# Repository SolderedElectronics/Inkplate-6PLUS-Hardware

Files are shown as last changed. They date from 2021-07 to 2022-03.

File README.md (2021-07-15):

# Inkplate 6PLUS Open Source Hardware files



Open Source Hardware (OSH) files for e-paper display Inkplate 6PLUS can be found in this repo. Inkplate 6PLUS is a powerful, energy-efficient, Wi-Fi-enabled ESP32 board with a recycled 6.0 inch e-paper display featuring touchscreen and front lighting. It is part of Inkplate family and it’s open hardware supported by an open-source software library, and it’s the easiest e-paper board to use, regardless of whether you prefer the Arduino IDE or MicroPython. Learn more about Inkplate 6PLUS on [Crowd Supply](https://www.crowdsupply.com/e-radionica/inkplate-6plus) or [official website](https://inkplate.io).

### Versions:
- v1.0. first, original version shipped to backers in 2021

### Misc
Inkplate 6PLUS is available for purchase via:
- [e-radionica.com](https://e-radionica.com/en/inkplate.html)
- [Crowd Supply](https://www.crowdsupply.com/e-radionica/inkplate-6PLUS)

For all questions and issues, please open an issue or thread on [our forums](http://forum.e-radionica.com/en/).
For sales & collaboration, please reach us via [e-mail](mailto:kontakt@e-radionica.com).

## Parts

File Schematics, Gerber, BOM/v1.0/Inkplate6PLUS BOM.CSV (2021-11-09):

Bill of Material for
On 9/14/2021 at 11:42:50 AM
Comment | Pattern | Quantity | Components
0R | 0603R | 1 | R11
100k | 0603R | 13 | R10, R22, R24, R25, R26, R29, R30, R33, R37, R38, R40, R41, R42
100nF - AC0603KRX7R8BB104 | 0603C | 2 | C14, C15
100nF | 0603C | 22 | C22, C23, C24, C27, C28, C31, C32, C34, C37, C38, C40, C43, C44, C48, C49, C50, C55, C59, C62, C64, C65, C66
100pF | 0603C | 1 | C33
10K | 0603R | 6 | R3, R4, R17, R21, R28, R39
10nF-AC0603KRX7R8BB103 | 0603C | 2 | C16, C17
10uF | 1206C | 3 | C20, C26, C42
10uF-GRM188R61E106KA73J | 0603C | 3 | C7, C9, C13
1206FUSE_500mA | 1206FUSE | 1 | F1
12pF | 0603C | 2 | C46, C47
15R | 0603R | 1 | R34
1K | 0603R | 6 | R9, R15, R27, R31, R32, R43
1M | 0603R | 2 | R5, R6
1uF | 0603C | 2 | C45, C53
2/3 pads connected | SMD_JUMPER 2/3 pads | 3 | JP1, JP2, JP4
2K49 | 0603R | 1 | R18
2u2 | 0603C | 6 | C21, C29, C30, C36, C39, C41
2u2-GRM188R61E225MA12D | 0603C | 2 | C18, C19
330R | 0603R | 1 | R14
3V3 | HEADER MALE 1x1 - NO_SILK | 1 | K21
43k-RC0603FR-0743KL | 0603R | 1 | R2
470R | 0603R | 1 | R13
47k | 0603R | 1 | R36
47k5-RC0603FR-0747K5L | 0603R | 1 | R7
4u7 | 0603C | 2 | C51, C52
4u7-TMK212AB7475KG-T | 0805C | 15 | C1, C2, C3, C4, C5, C6, C8, C10, C11, C12, C54, C58, C60, C61, C63
510K | 0603R | 1 | R16
52k3-RC0603FR-0752K3L | 0603R | 1 | R8
5k1 | 0603R | 3 | R19, R20, R35
7LC32768F12UC | 3215Crystal | 1 | X1
AP5726WG-7 | SOT-23-6 | 1 | U10 | inkplate 6+
BAT20J | SOD-323 | 1 | D8
BAT54S | SOT-23-3 | 4 | D3, D4, D5, D6 | SINGLE SHOTTKY DIODE
CH340C | SOP-16 | 1 | U9
CL21B105KBFNNNG | 0805C | 2 | C56, C57
CR2032-BS-6-1 | CR2032-BS-6-1 | 1 | K33
CUS10F30,H3F | SOD-323 | 2 | D1, D2
DIODA M4 | DIODA SMA | 2 | D9, D10
DNP | 0603R | 2 | R12, R23
DNP | 2917C | 2 | C25, C35
DNP | SOT-23-3 | 1 | Q1
easyC SMD | EasyC connector | 1 | K22
ESP32-WROVER | ESP32-WROVER | 1 | U3
GND | HEADER MALE 1x1 - NO_SILK | 1 | K26
GPB1 | HEADER MALE 1x1 - NO_SILK | 1 | K1
GPB5 | HEADER MALE 1x1 - NO_SILK | 3 | K9, K11, K15
HEADER 1x1 | HEADER MALE 1x1 - NO_SILK | 17 | K2, K3, K4, K5, K6, K7, K8, K10, K12, K13, K14, K16, K17, K18, K19, K27, K28
HEADER 8x1 | HEADER MALE 8x1 - NO_SILK | 2 | K20, K23
HYC77-TF09-200 | HYC77-TF09-200 | 1 | K29 | MicroSD Inkplate
Inkplate_TP | Inkplate test header | 1 | K36
JST 2pin | JST 2PIN SMD | 1 | K30
K2-1114SA-A4SW-06 | K2-1114SA-A4SW-06 | 2 | S2, S4 | Inkplate
KILL | HEADER MALE 1x1 - NO_SILK | 1 | K32
left connection | SMD_JUMPER 2/3 pads left connection | 1 | JP3
LQH44PN4R7MP0L | LQH44PN4R7MP0_Inductor | 1 | L1 | Inductor Power Chip Shielded Wirewound 4.7uH 20% 1MHz Ferrite 1.7A 96mOhm DCR 1515 Embossed T/R
LTST-S270TBKT | 0603 Side view LED LTST-S270GKT | 1 | D12
MC14093BDTR2G | TSSOP-14 | 1 | U8 | Inkplate
MCP23017T-E/SS | SSOP-28 10.20x5.30mm | 2 | U2, U4
MCP47A1T-A0E/LT | MCP47A1 SOT-23-6 | 1 | U11 | Inkplate 6+
MCP73831T-2ACI/OT | SOT-23-5 | 1 | Q3
NMOS | SOT-23-3 | 2 | Q6, Q13
NPN | SOT-23-3 | 3 | Q4, Q7, Q9
NR4012T220M | NR4012T2R2M_Fixed Inductor | 1 | L3 | FIXED IND 2.2UH 1.2A 108 MOHM
NR4012T2R2M | NR4012T2R2M_Fixed Inductor | 1 | L2 | FIXED IND 2.2UH 1.2A 108 MOHM
NTC-NCP18XH103F03RB | 0603R | 1 | R1
PAD | PAD4x4 | 9 | PAD1, PAD2, PAD3, PAD4, PAD5, PAD6, PAD7, PAD8, PAD9
PCF85063ATL/1,118 | DFN-10 | 1 | U7
PMOS | SOT-23-3 | 5 | Q5, Q11, Q12, Q14, Q15
Pushbutton SMD | Pushbutton SMD | 1 | S1
RB510SM-40FHT2R | RB510SM-40FHT2R SOD523-2 | 1 | D11 | Inkplate 6+
RED | 0603LED | 1 | D7
SCL | HEADER MALE 1x1 - NO_SILK | 1 | K24
SDA | HEADER MALE 1x1 - NO_SILK | 1 | K25
SFV34R-3STBE1HLF | SFV34R-3STBE1HLF | 1 | K34
SFV6R-1STBE1HLF | SFV6R-1STBE1HLF | 1 | K35 | CONN FFC BOTTOM 6POS 0.50MM R/A
SFV8R-1STBE1HLF | SFV8R-1STBE1HLF | 1 | K37 | Conn FPC Connector SKT 8 POS 0.5mm Solder RA SMD Embossed T/R
SK-3296S-01-L1 | SK-3296S-01-L1 | 1 | S3
SN74LVC1G34DBV | SOT-23-5 | 1 | Q2 | Inkplate
SSM3J358R,LF | SOT-23-3 | 2 | Q8, Q10
TPS3840PL27DBVR | TPS3840PH30DBVR | 1 | U5
TPS65186RGZR | TPS65186_QFN_48 | 1 | U1 | IC PWR MGMT E INK 48VQFN
TPS7A2633DRVR | TPS7A2633DRVR | 1 | U6
TXS0104EPWR | SOP-14 | 1 | U12
U262-161N-4BVC11 | U262-161N-4BVC11 | 1 | K31 | Inkplate

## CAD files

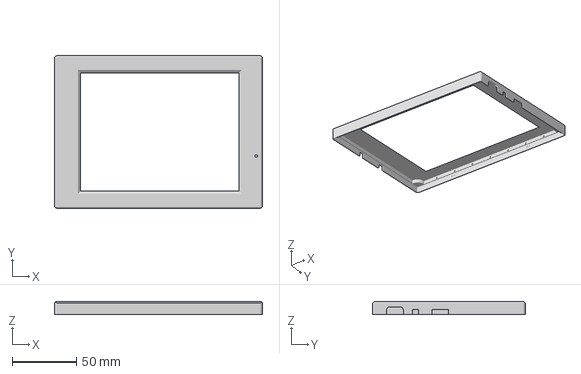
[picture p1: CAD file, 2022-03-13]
3D printable case/alternate case/Cover.3mf
161.6 x 118.6 x 10.0 mm

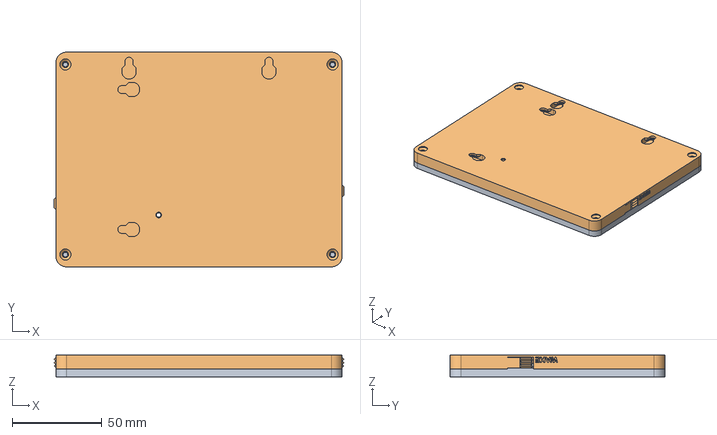
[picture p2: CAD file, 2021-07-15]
3D printable case/Original case/Inkplate6PLUS_Case_v1.1.step
161.7 x 119.7 x 12.0 mm
Inkplate6PLUS_Case_Top
Inkplate6PLUS_Case_Bottom

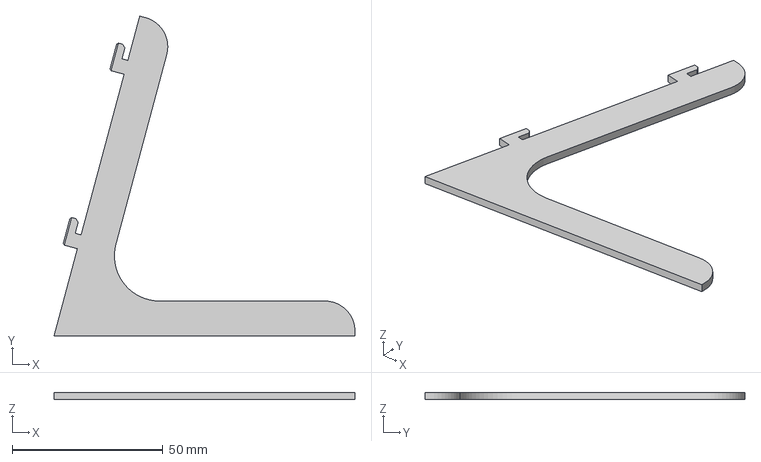
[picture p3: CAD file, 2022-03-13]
3D printable case/alternate case/Desk mount bracket.3mf
100.0 x 106.3 x 2.30 mm

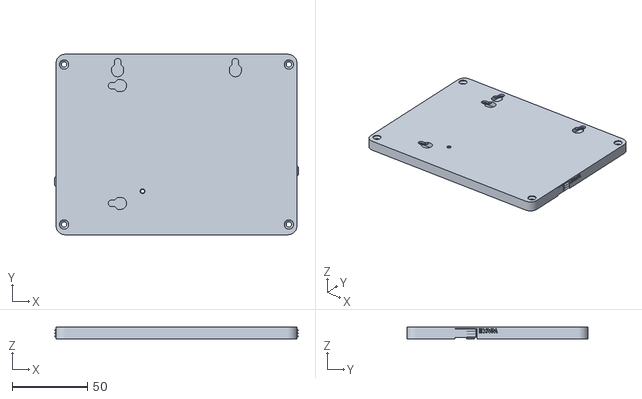
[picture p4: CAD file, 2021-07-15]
3D printable case/Original case/Inkplate6PLUS_Case_Bottom_v1.1.stl
161.7 x 119.7 x 7.80

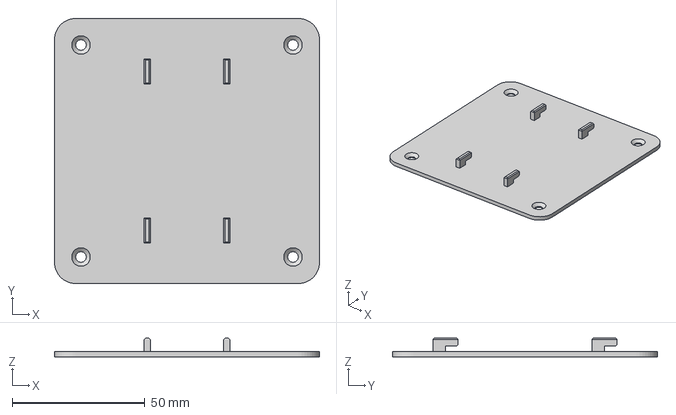
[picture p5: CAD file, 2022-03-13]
3D printable case/alternate case/Wall bracket.3mf
100.0 x 100.0 x 7.00 mm

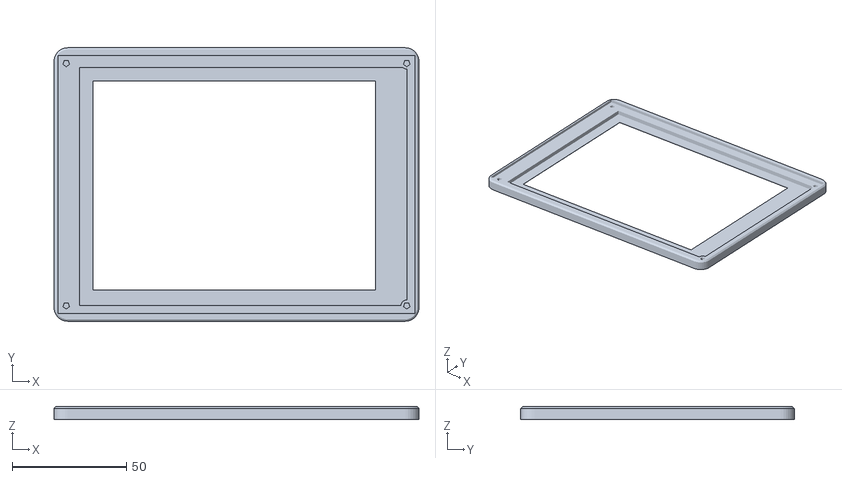
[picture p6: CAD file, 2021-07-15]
3D printable case/Original case/Inkplate6PLUS_Case_Top_v1.1.stl
159.7 x 119.7 x 5.60

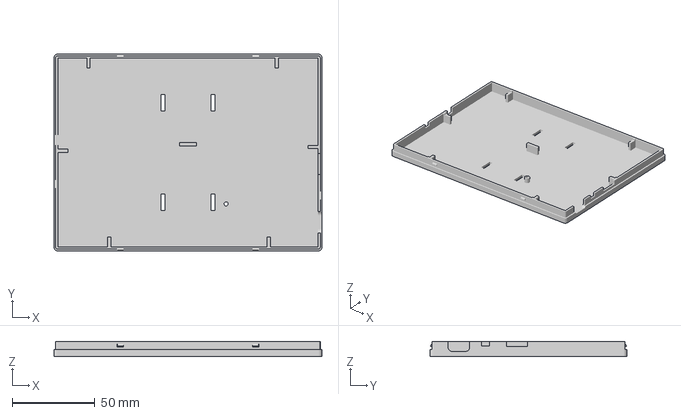
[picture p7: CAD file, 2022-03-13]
3D printable case/alternate case/Base.3mf
161.6 x 118.6 x 9.20 mm

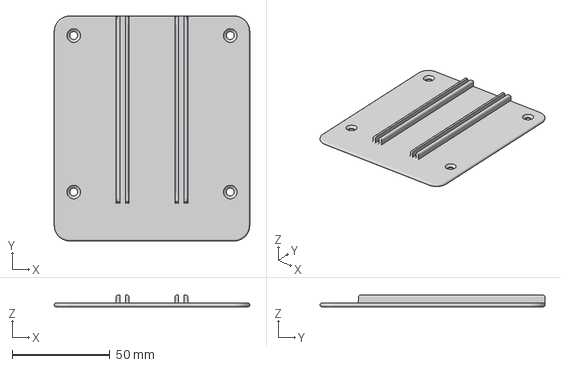
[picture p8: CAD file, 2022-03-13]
3D printable case/alternate case/Desk mount base.3mf
100.0 x 115.0 x 6.00 mm

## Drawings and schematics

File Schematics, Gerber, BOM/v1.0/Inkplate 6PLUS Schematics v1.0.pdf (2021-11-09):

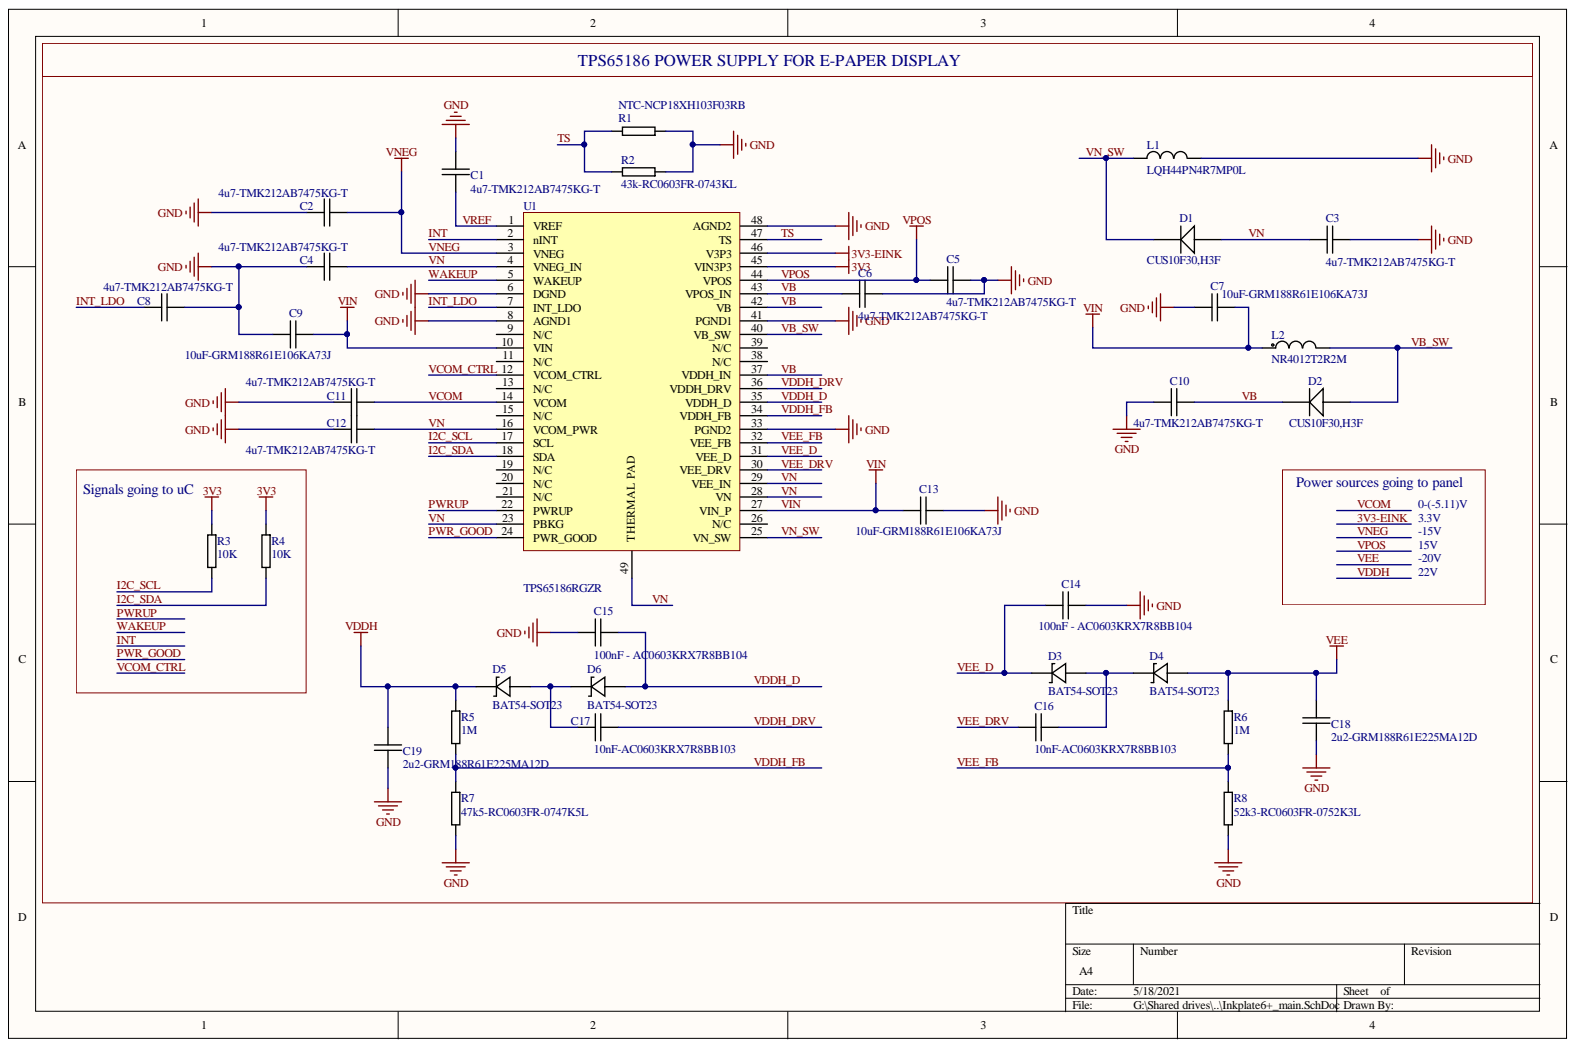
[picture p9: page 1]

TPS65186 POWER SUPPLY FOR E-PAPER DISPLAY

INT_LDO | INT_LDO 7 AGND1 8 | VB | VIN

Power sources going to panel

Signals going to uC

Size A4 | Number | Revision

Date: 5/18/2021 | Sheet of
File: G:\Shared drives\..\Inkplate6+_main.SchDoc Drawn By:

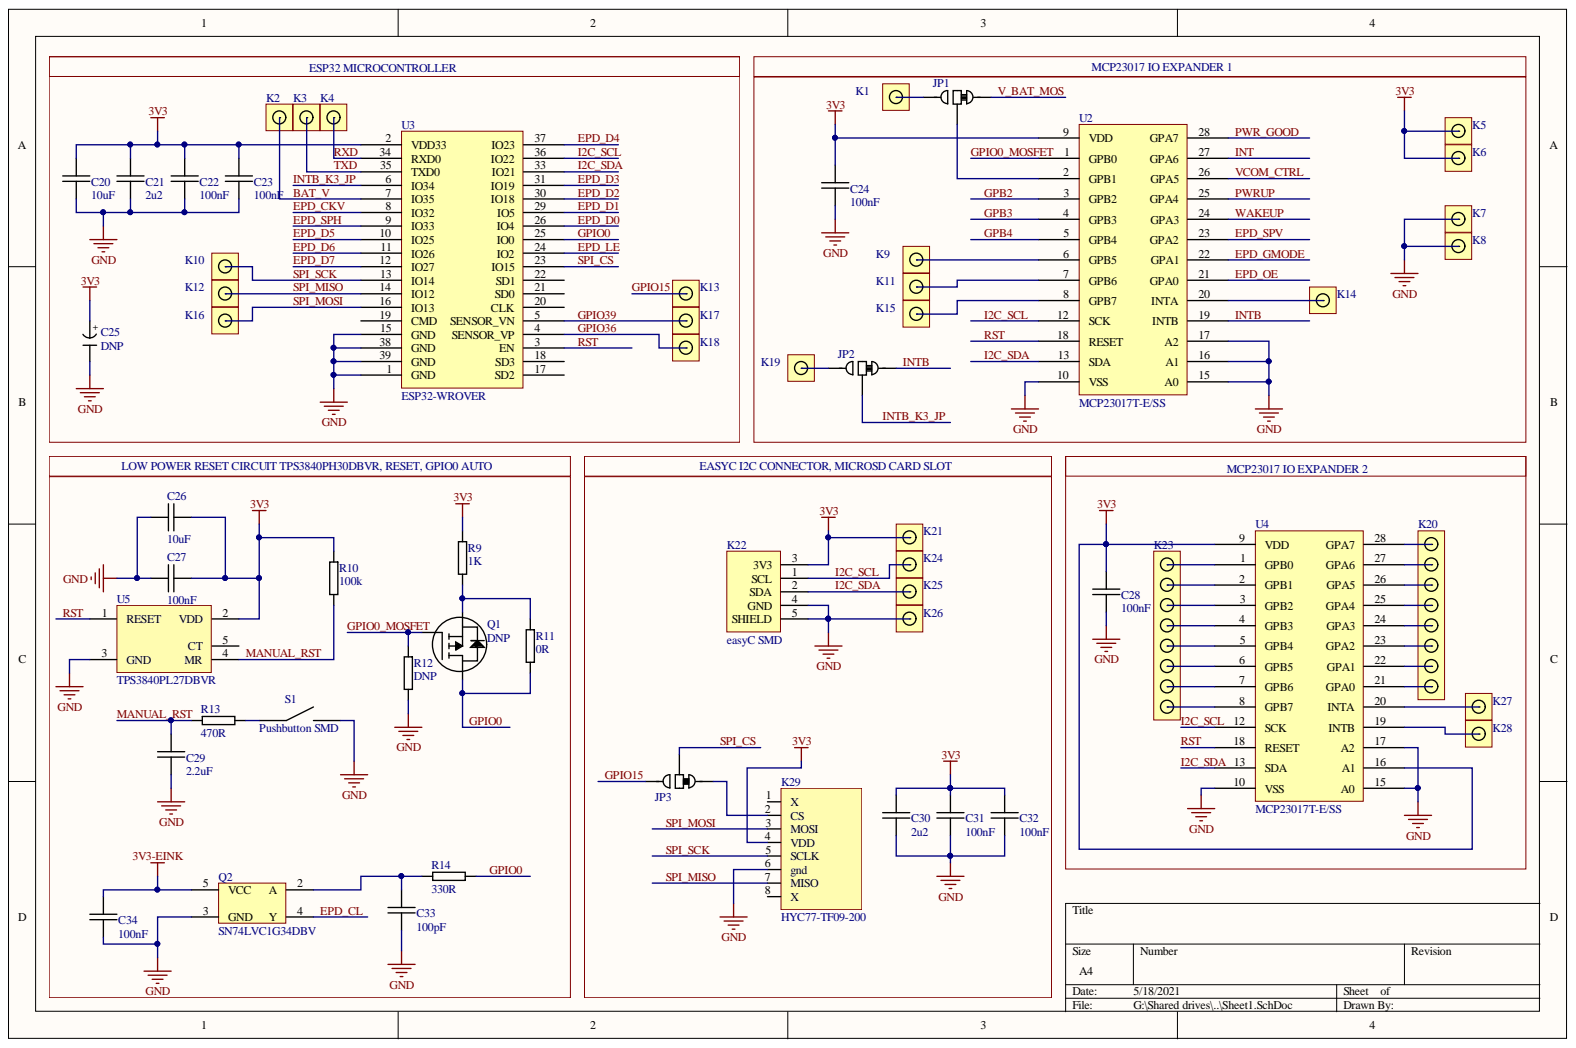
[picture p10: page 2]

RXD

GPIO0_MOSFET | GPB0 1 | INT

CMD 19

SCK 12

GND 38 | | RST

LOW POWER RESET CIRCUIT TPS3840PH30DBVR, RESET, GPIO0 AUTO

Size A4 | Number | Revision

Date: 5/18/2021 | Sheet of
File: G:\Shared drives\..\Sheet1.SchDoc | Drawn By:

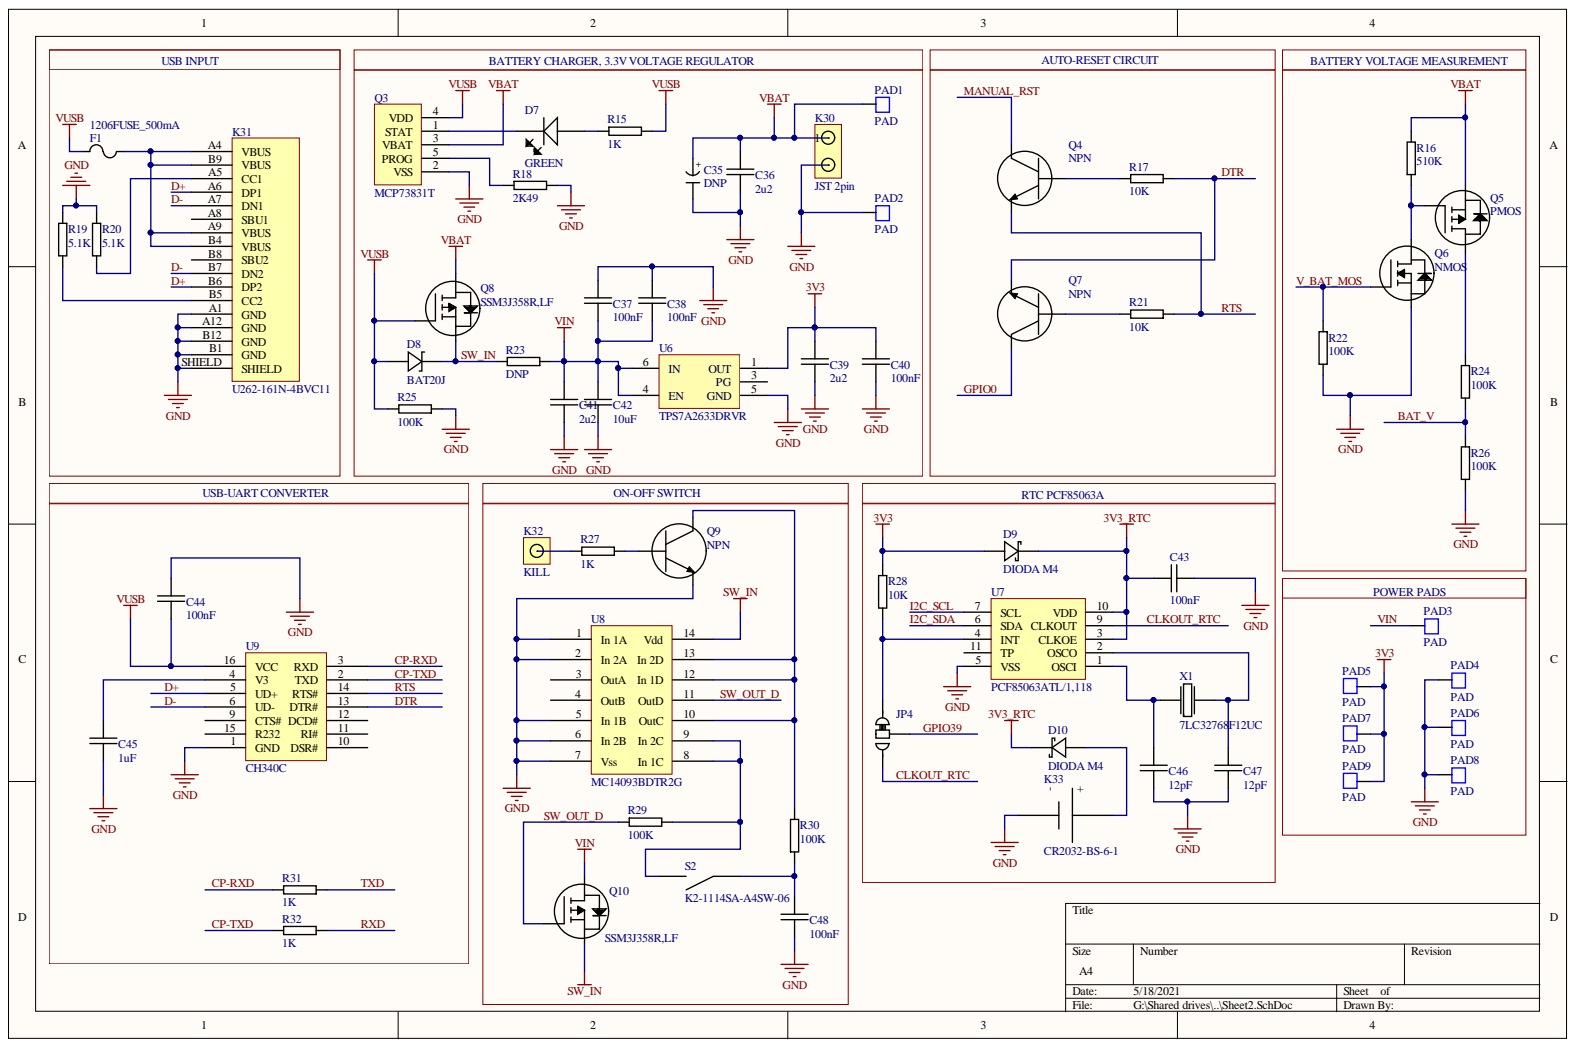
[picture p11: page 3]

BATTERY CHARGER, 3.3V VOLTAGE REGULATOR

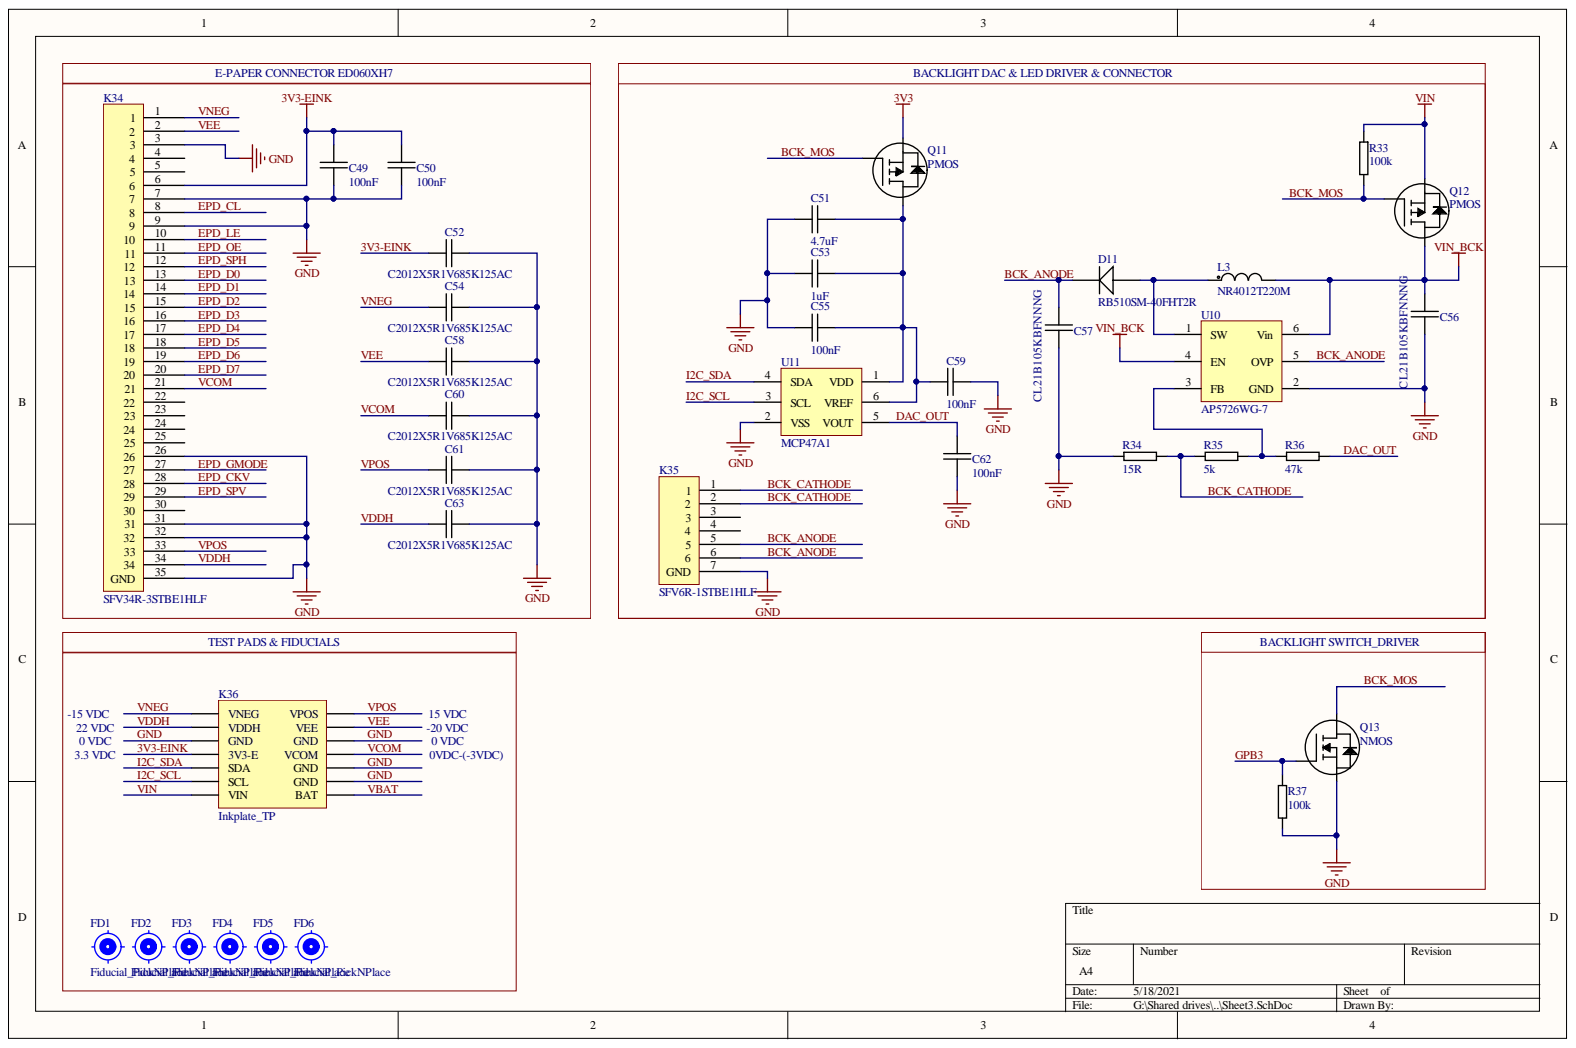
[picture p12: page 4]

BACKLIGHT DAC & LED DRIVER & CONNECTOR

Size A4 | Number | Revision

Date: 5/18/2021 | Sheet of
File: G:\Shared drives\..\Sheet3.SchDoc | Drawn By:

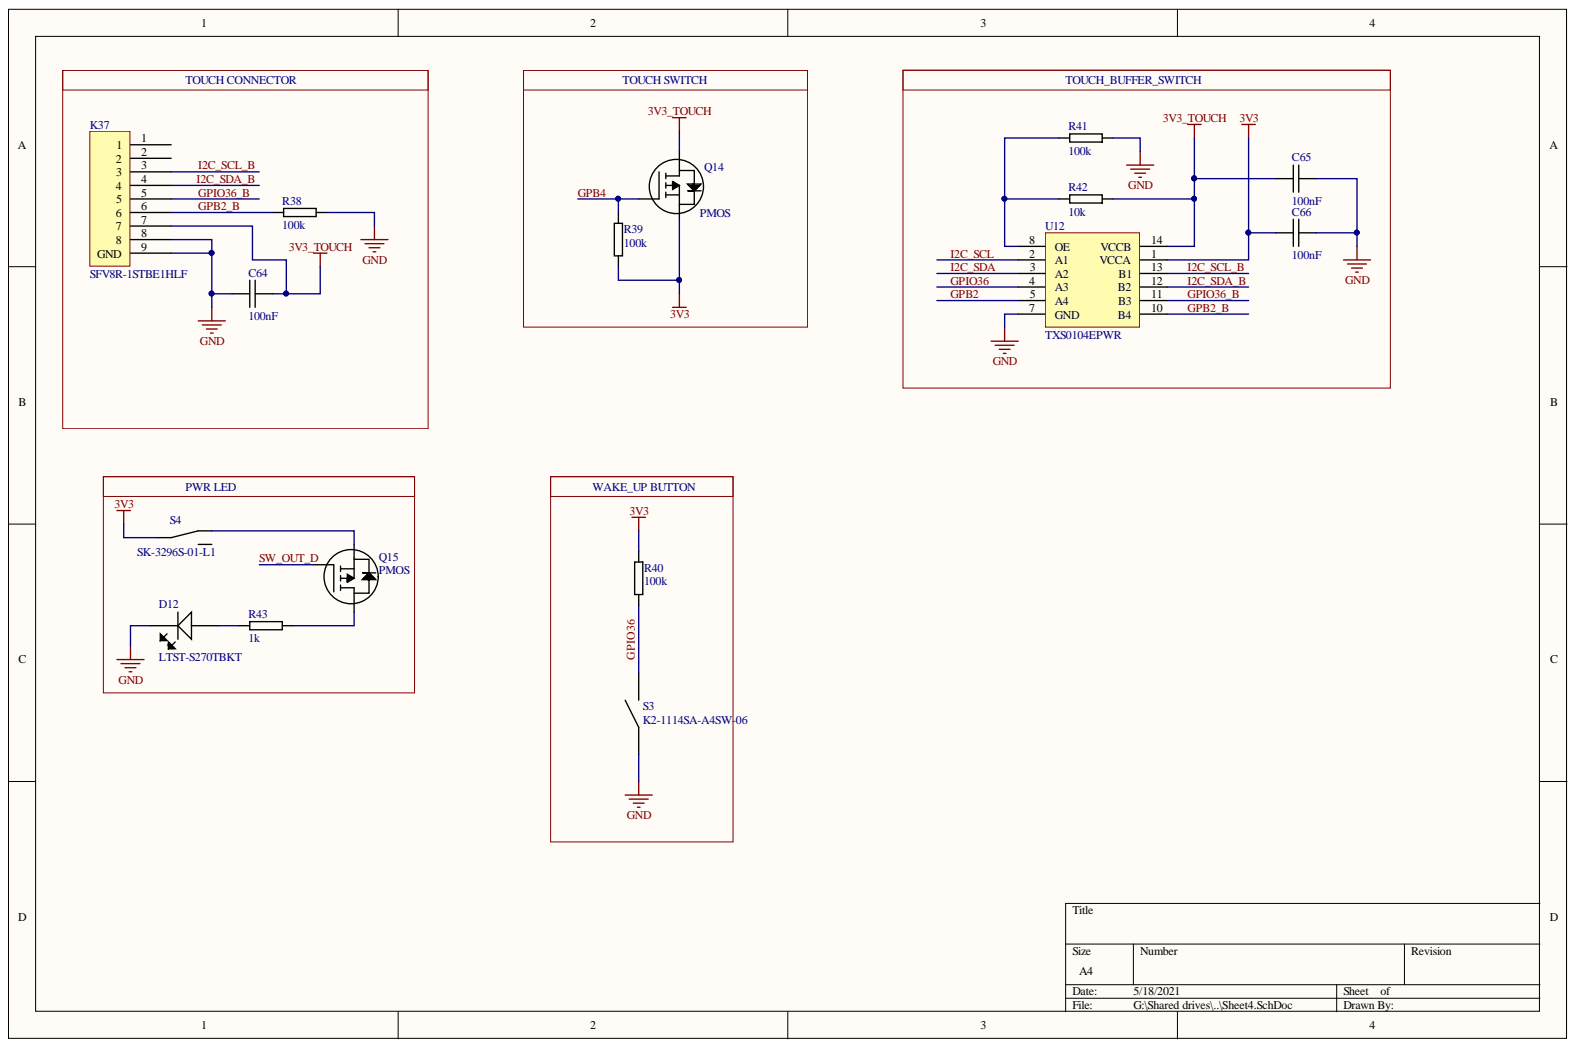
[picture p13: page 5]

S i z e | Nu mber | Rev i s i o n

5/1 8/2 0 2 1 | Sheet o f

Fi le: G :\S hared dri ves\. .\S heet4 . Sch D o c | D raw n B y :

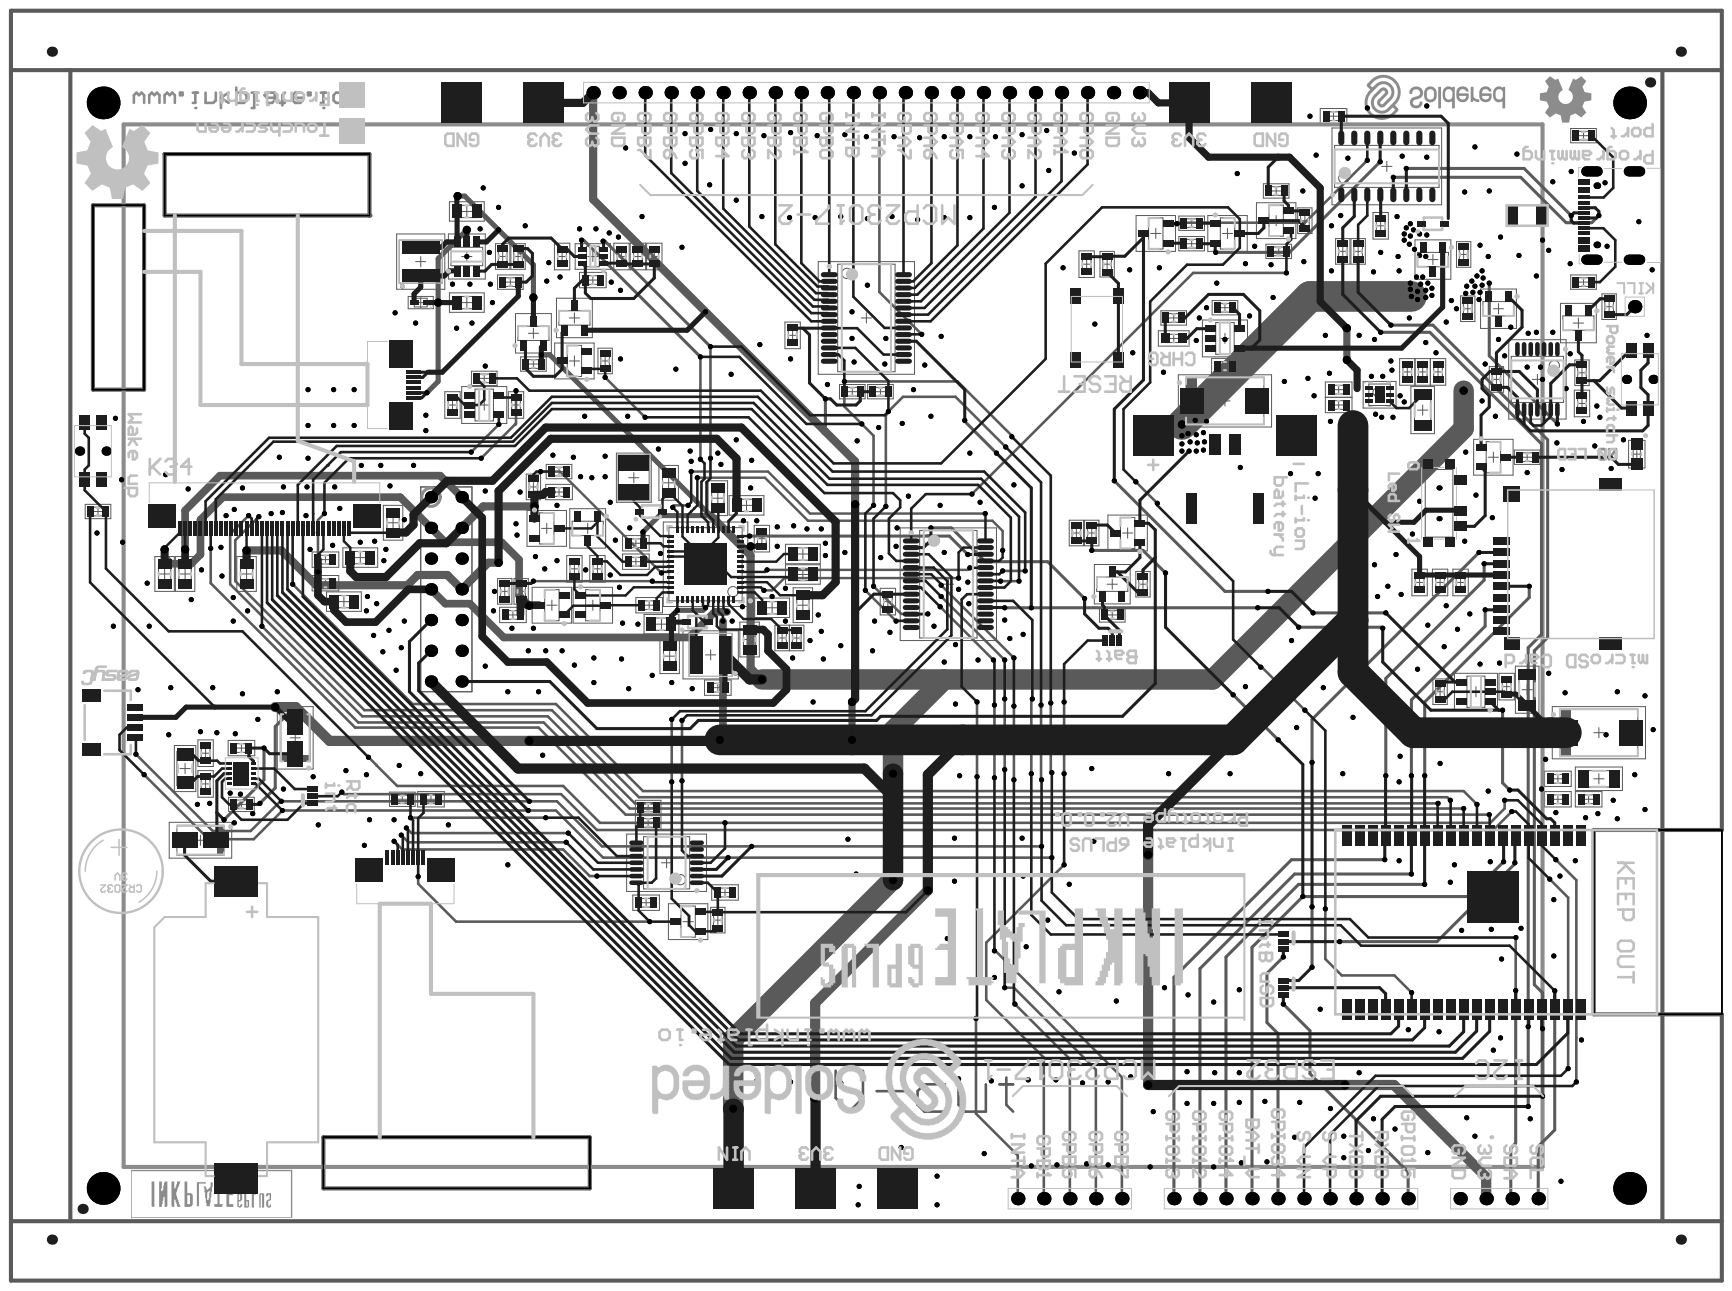
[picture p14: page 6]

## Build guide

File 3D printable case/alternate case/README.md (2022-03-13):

### Snap case and brackets for Inkplate 6PLUS

Another case design for the Inkplate 6PLUS. This case requires no screws, instead the cover snaps onto the base. Mounting
as designed is via 4 slots in the back, and there are accompanying brackets for wall or desk mounting.

The test example was printed in PLA on a Makergear M3 printer. Supports are not required except for the wall
bracket.

Included are 3mf files for all components, ready to import into a slicer, but also the Fusion360 source, allowing
modifications to be made.

Note that for the desk stand two of the "Desk mount bracket" pieces are required.

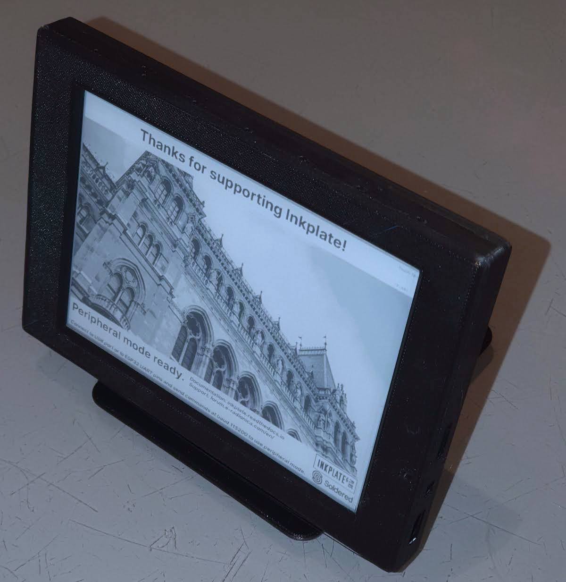
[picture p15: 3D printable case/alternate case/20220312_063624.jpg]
Front view of desk mount


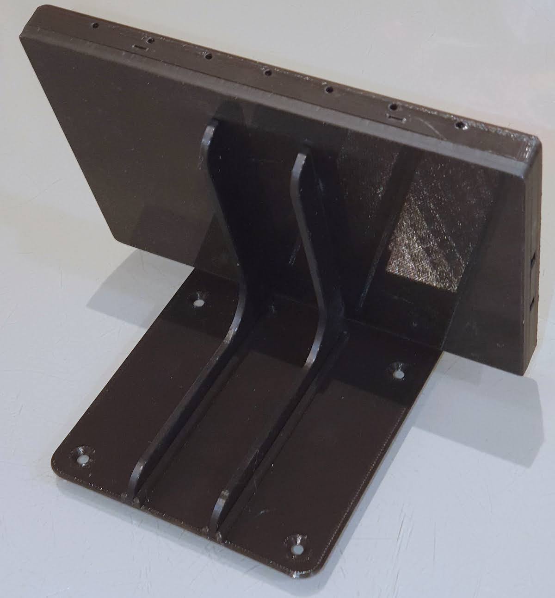
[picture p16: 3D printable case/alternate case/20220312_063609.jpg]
Rear view of desk mount


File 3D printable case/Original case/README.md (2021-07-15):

3D printable case. Can fit Prusa MK3S(+) bed. Printed in [PLA Space](https://e-radionica.com/en/e-radionica-com-special-filament-1-75mm-space.html).

Screws: M3 x 10mm countersunk, 4 pieces, any head (HEX prefferable)

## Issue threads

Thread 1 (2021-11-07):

Schematics and Gerber/Layout Files

DerNuntius, 2021-11-07:
Hi,
Thank you for designing a refined version of the Inkplate hardware.
The Inkplate 6 Plus is marketed as an OSH compliant product but I was not able to find the schematics and layout files.
It would be nice to have them aswell.

Best Regards

Hugo Melder

davidzovko, 2021-11-09:
Hi Hugo, just [added](https://github.com/e-radionicacom/Inkplate-6PLUS-Hardware/commit/5059d883c2a7ebd4e57609ba5fb4a4fa1fa918e5), please check!

Closed 2021-11-09.

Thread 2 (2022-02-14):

Step file corrections

P-Storm, 2022-02-14:
Hi,

I was looking into how big a battery may be in the enclosure that is linked in the repository, and I noticed the following:

- The rotation of the PCB was 180 degrees off.
- The circuit board doesn't fit in enclosure, some scaling issue? Below some pictures.

SD Card slot not center: 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
Screw holes not aligning:
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

Are some of those design files old or am I missing something?

Kind regards.

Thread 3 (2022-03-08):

Is there an f3d file for this case?

clydebarrow, 2022-03-08:
It is provided for the original Inkplate 6, but not for the plus.

davidzovko, 2022-03-08:
Added with https://github.com/e-radionicacom/Inkplate-6PLUS-Hardware/commit/e534992d60d3f1a4e5385466133c81a321928030 :)

clydebarrow, 2022-03-09:
Thanks. I had already started doing my own, but the 3D model of the board came in useful (though it's missing the RTC battery and the display.)

My version attached. This is a snap-lock case - no screws.

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

[Inkplate 6+ case v19.zip](https://github.com/e-radionicacom/Inkplate-6PLUS-Hardware/files/8214406/Inkplate.6%2B.case.v19.zip)

davidzovko, 2022-03-09:
Thanks for that, if you want to, make a new folder in the 3D enclosure folder and make a Pull request, I'll add it to the repo

clydebarrow, 2022-03-09:
Ok, will do.

Closed 2022-03-08.

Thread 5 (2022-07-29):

specifications/pinouts for the eInk display?

claud9999, 2022-07-29:
Where I could find reference material for the eInk display?

Thanks for the schematics and I've been able to find good documentation on the various chips but not for the display itself.

davidzovko, 2022-08-01:
Hi, you are looking for ED060XH7 part number for the e-paper display. Since a lot of stuff there is under the NDA, you need to google and see what you can find. We did the same. Good luck!

Closed 2022-08-01.

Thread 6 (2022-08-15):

add pull-up resistor for GPIO36?

claud9999, 2022-08-15:
Per the ESP32 documentation,

_GPI: GPIO34-39 can only be set as input mode and do not have software-enabled pullup or pulldown functions._

https://docs.espressif.com/projects/esp-idf/en/latest/esp32/api-reference/peripherals/gpio.html

I believe this is why I'm seeing unreliable behavior (for example, the `Inkplate_Basic_Touchscreen_Draw` demo code reports `Touchscreen init fail` on some boots) as the touchscreen as the GPIO is "floating". I'm not great with electronics design, I'm wondering if there's a simple way to solder a pull-up resistor onto some pads to always pull up GPIO36?

See also: https://github.com/e-radionicacom/Inkplate-Arduino-library/issues/153

ifadiga, 2022-08-16:
Hello,

Inkplate 6PLUS already has a pull-up resistor on GPIO36 (On sheet 5 in the Wake-up button circuit). Maybe you have a problem with something else on your Inkplate.

Try to reconnect the touch cable and see what happens. If you have problems after that, feel free to contact us.

claud9999, 2022-08-16:
Thanks Ivan, I think much of my issue was my own bad Arduino coding style. Sometimes the touchscreen doesn't init properly (true even with examples provided) but a re-power seems to fix. The Inkplate Arduino code tries to set a pullup resistor so I wasn't sure.

Closed 2022-08-16.

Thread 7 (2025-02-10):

Please document how to use GND/3V3/VIN pads

mmccool, 2025-02-10:
I would like to power the board from the VIN/GND pad on the back.   However, I can't find documentation anywhere on what voltages to use (I'm assuming 5V, but would like confirmation).   Also, I assume the 3V3 pad is the *output* from the regulator and I should leave it disconnected.  I'm also assuming I should NOT connect the USB and external power at the same time, but if that is the case it should be documented.

Background: I plan to hang this on the wall as a Home Assistant status display, and want to power it from a POE port in the wall.  I can arrange to get either 12V (which I don't plan to use unless I need to) or 5V from another POE device (a wESP32).

It would also be useful to document the current requirements.  Is is 5V 1A?  5V 2A?  What are the power requirements of the touchscreen and the backlight?  (See comment below: it seems these cannot be used together at full power...).

rsoric, 2025-02-19:
Hi @mmccool ,

thanks for your question, and sorry for the late reply. It was good you contacted us over support to get a more urgent reply here, so I'll write what I said here in case any other user is looking for a reply:

VIN can go up to 5V and the current requirement: 0.5A should be about the max. and 1A should be more than enough.

^That was my original reply, after consulting with the hardware team I was advised to say 0.6A as the maximum current spike approximation. It seems to me your POE system will work just fine for Inkplate 6 PLUS.

I checked and we unfortunately don't have on hand one of these older versions of Inkplate 6 PLUS on hand (from your email I see it's the older version), so I'm not able to try and replicate your issue at the moment. It will be documented in the new Inkplate documentation [docs.inkplate.com](docs.inkplate.com).

Hope that helps
-Rob

mmccool, 2025-02-19:
Thanks very much for your answer!  It would still be good to put this in the docs somewhere.

As it happens I decided to power the system over USB using a “PoE+ Splitter” instead of a wESP to avoid having to solder things to pads on the back once I realized the frame I was making could give me room to hide the USB cable… but it is good to know the power requirements too.  The value you gave aligns with what I have been measuring (using a Zigbee power-monitoring switch, which is however not reliable at very low power levels, although I just realized I COULD use a USB C power-measuring dongle I have… somewhere).

As an aside not directly related to this issue, it’s a bit annoying I have to press the button to turn it on.   I would prefer if it turned on automatically when power is applied since if I lose power (which happens a lot where I live…) I’ll have to pull it off the wall to switch it back on.   But this is a minor issue, maybe provide the option in a future hardware version?  Maybe the new versions already allow for this?

Anyway, thanks again, issue can be marked resolved (ideally, once you add the info to the docs).  Great product, even though I have the very first version!

Closed 2025-02-19.

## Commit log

2021-07-15 Add 3D printable case & README
    [Inkplate6PLUS_Case_Bottom_v1.1.stl, Inkplate6PLUS_Case_Top_v1.1.stl, Inkplate6PLUS_Case_v1.1.step]
2021-11-09 Add v1.0. open source files
    [Inkplate6PLUS BOM.CSV]
2022-03-13 Add alternate case
    [Base.3mf, Cover.3mf, Desk mount base.3mf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]
